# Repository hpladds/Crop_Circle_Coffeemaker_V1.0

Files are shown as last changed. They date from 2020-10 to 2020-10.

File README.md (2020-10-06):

The code for the Ridiculous Coffee Machine  (AKA Crop Circle Coffeemaker) consists of python scripts that control the movement of the machinery and one a Bash script that calls the individual python scripts at the appropriate times.

A pair of python scripts control each motor: one script (with the "cw" designation) turns the motorshaft in a clockwise direction, the second script (with a ccw designation) turns the motorshaft in a counterclockwise direction.

For example: Script "1_cw.py" turns the shaft of motor 1 in a clockwise direction. Script "1_ccw.py" turns the motorshaft in a counterclockwise direction. 

From the Linux command line the following will rotate the motor's shaft at a rate of 1 step/millisecond for 10 steps:

$ python 1_cw.py 1 10

Each motor is fitted with a pulley gear wound with a cable. As the motorshaft rotates, the cable is either reeled in or out, and each motor works as a cable actuator. Three of these cable actuators are connected to central "effector" thereby creating a "Cable Robot."

The python script, "move_dist.py" coordinates the actions of the three stepper motors (the cable actuators) so as to control the movement of the "effector." Movement of the coffee cup is acheived by placing it upon the effector and executing the move_dist.py script.

Pouring water from the kettle is controlled with the Bash script "brew_flow.sh"  

"Brew.sh" is the script that initiates the brewing.

# Crop_Circle_Coffeemaker_V1.0

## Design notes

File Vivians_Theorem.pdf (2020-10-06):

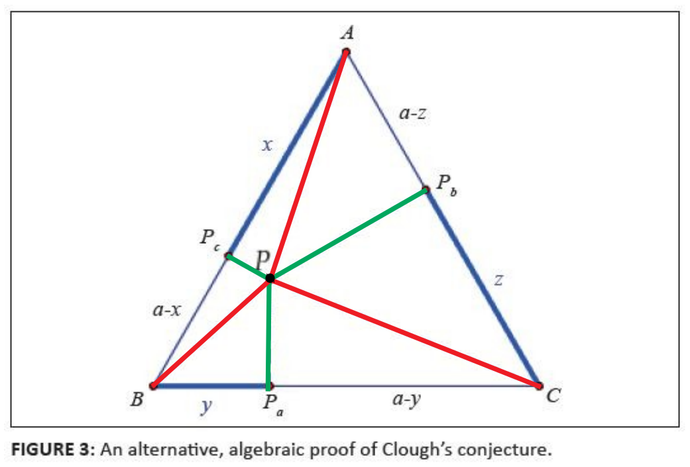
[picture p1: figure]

Viviani’s Theorem states that the sum of the lengths of the green lines will be constant irrespective of the position of P. https://en.wikipedia.org/wiki/Viviani%27s_theorem

Clough’s Theorem states that the sum of the lengths of the blue lines will also be constant irrespective of P’s position. https://ggijro1.files.wordpress.com/2013/12/art44311.pdf

Question???

Doesn’t this imply that the sum of the red lines (the hypotenuse) would also be constant irrespective of the P’s placement?

The Internet seems conspicuously empty of any confirmation of this bit of conjecture.

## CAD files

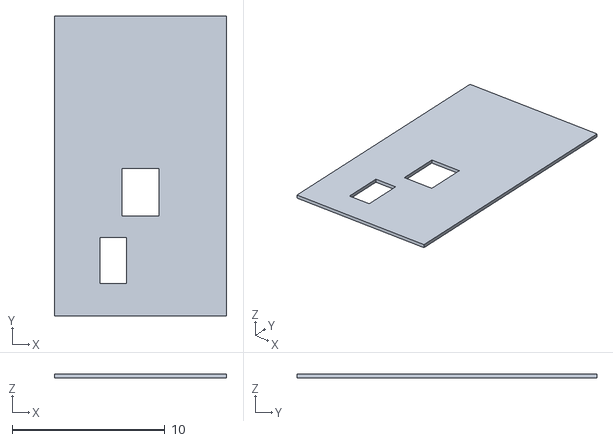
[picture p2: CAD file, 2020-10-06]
Base_Construction/STL/Bottom/Board_cutouts.stl
11.2 x 19.6 x 0.25

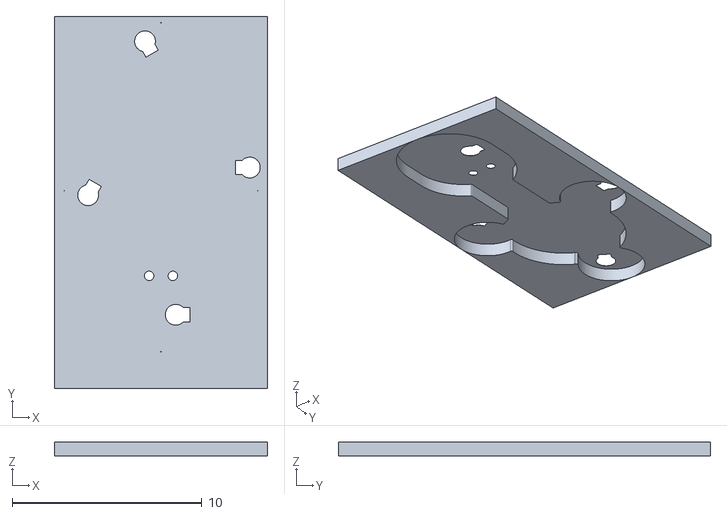
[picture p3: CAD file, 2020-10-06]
Base_Construction/STL/top/Through_holes.stl
11.2 x 19.6 x 0.76

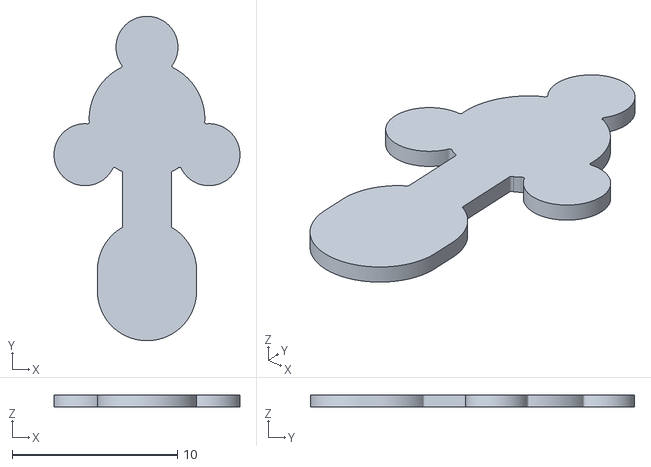
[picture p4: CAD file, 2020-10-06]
Base_Construction/Trash/Trying_To_Make_Bottom_Pockets/Push_Button_Pocket.stl
11.2 x 19.6 x 0.75

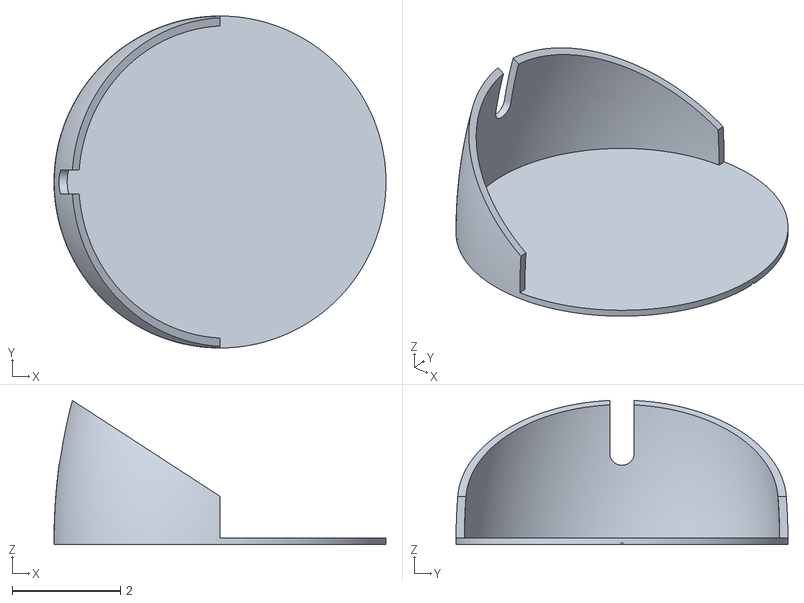
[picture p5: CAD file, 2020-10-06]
Kettle_Bracket_Platform/Kettle_Holder.stl
6.12 x 6.12 x 2.66

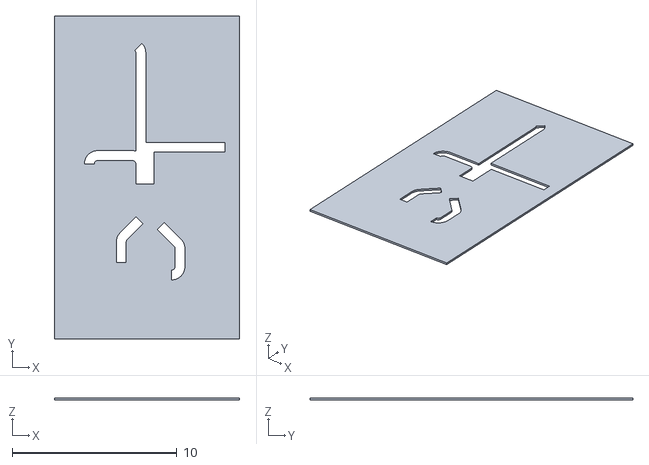
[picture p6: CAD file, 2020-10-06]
Base_Construction/STL/Bottom/wire_channel_cut_out.stl
11.2 x 19.6 x 0.125

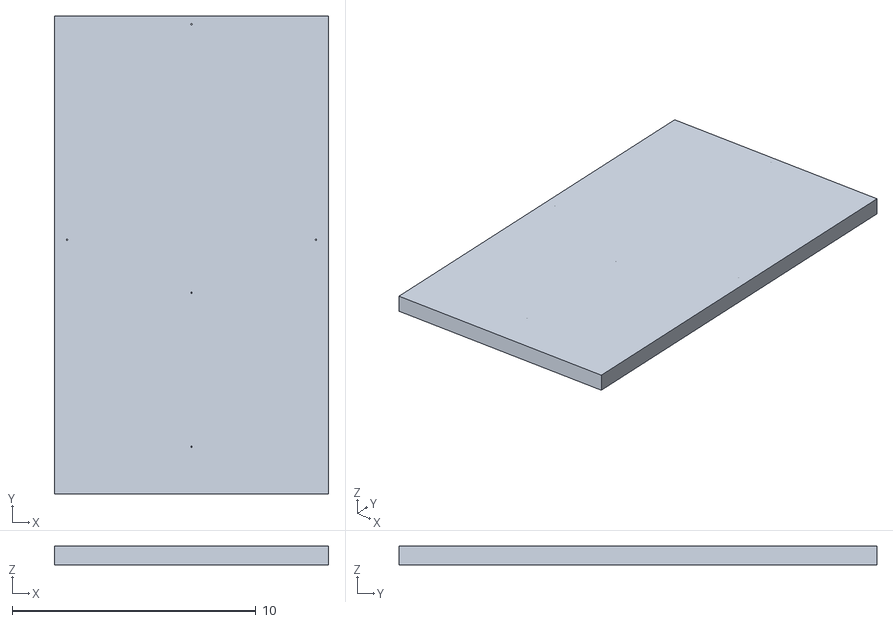
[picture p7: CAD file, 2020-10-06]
Base_Construction/STL/top/markings.stl
11.2 x 19.6 x 0.76

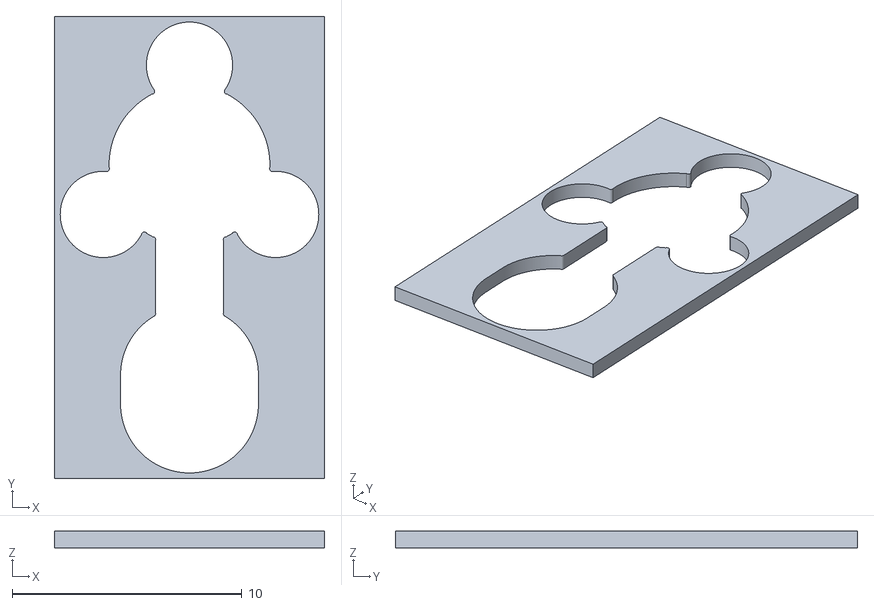
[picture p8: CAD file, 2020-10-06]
Base_Construction/STL/Bottom/Outer_Perimeter_Cut_bottom.stl
11.8 x 20.1 x 0.73

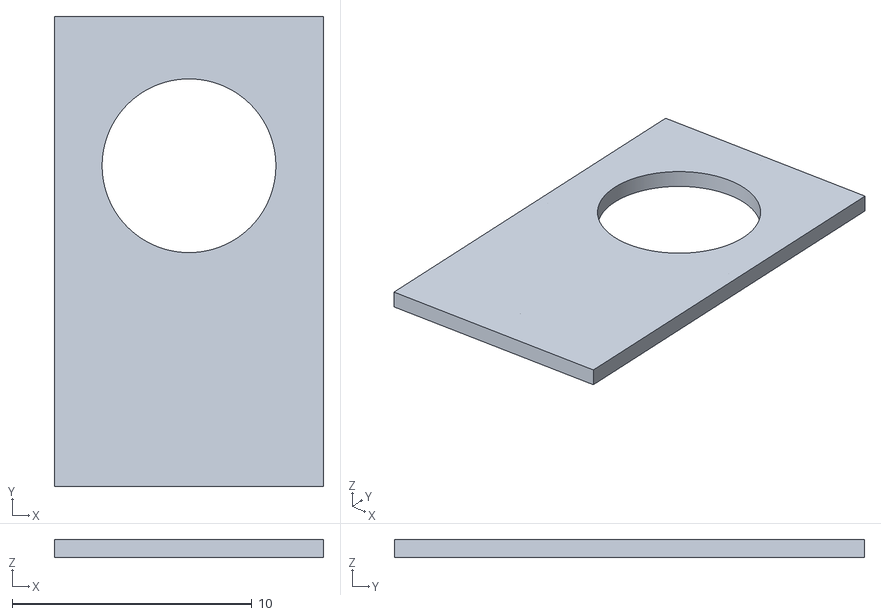
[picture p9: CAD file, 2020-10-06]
Base_Construction/STL/top/Platform.stl
11.2 x 19.6 x 0.76

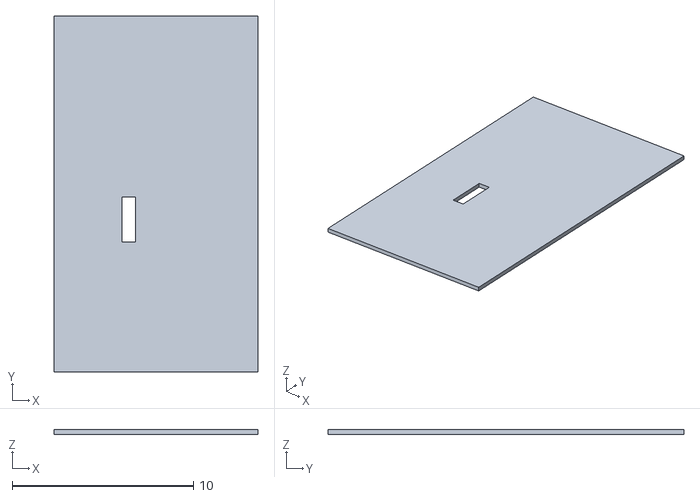
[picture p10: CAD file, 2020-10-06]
Base_Construction/STL/Bottom/Outlet_cutout.stl
11.2 x 19.6 x 0.25

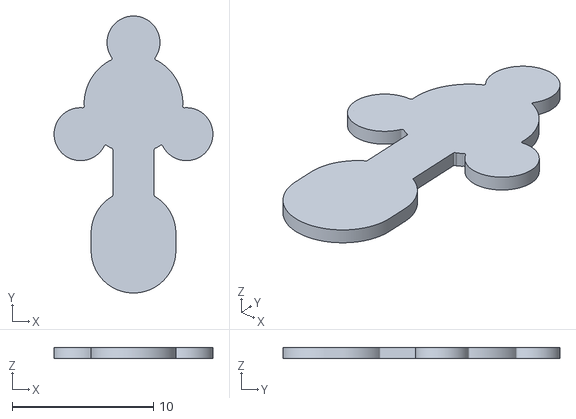
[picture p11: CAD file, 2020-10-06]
Base_Construction/Trash/Trying_To_Make_Bottom_Pockets/Channel2.stl
11.2 x 19.6 x 0.75

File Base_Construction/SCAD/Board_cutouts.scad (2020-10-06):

module channel1(){
    rotate ([0,0,270])
        rotate_extrude(angle=90, $fn = 300)
            translate([.5, .0485]) square([.6,.2247],true);
    
    translate([0,1.11,-.001])
        rotate_extrude(angle=45, $fn = 300)
            translate([.5, .0485]) square([.6,.2247],true);
    
    translate([.2,-.01,-.064])
        cube([.6, 1.125,.225],false);
    
    translate([.15, 1.243,-.064])
    rotate ([0,0,45])
        cube([.6, 1.45,.225],false);
}

module channel2(){  
    translate([-1.863, -8.75,-.064])
        cube([.6, 1.25,.225],false);
   
    translate([-1.0625, -7.5,-.001])
    rotate ([180,0,180])
        rotate_extrude(angle=45, $fn = 300)
            translate([.5, -.0485]) square([.6,.225],true);
    
      translate([-.245, -6.4,-.064])
      rotate ([0,0,135])
        cube([.6, 1.37,.225],false); 
}

module channel3(){

    translate([-.875, 4,-.001])
        rotate_extrude(angle=45, $fn = 300)
            translate([.5, 0.0485]) square([.6,.225],true);
    
        translate([-3, -2.75,-.001])
    rotate([0,0,90])
        rotate_extrude(angle=90, $fn = 300)
            translate([.5, 0.0485]) square([.6,.225],true);
    
        translate([-.875, -2.75,-.001])
        rotate_extrude(angle=90, $fn = 300)
            translate([.5, 0.0485]) square([.6,.225],true);
    
    translate([-.675, -3.975,-.064])
        cube([.6, 8,.225],false);
    
    translate([4.75, -2.04,-.064])
    rotate([0,0,90])
        cube([.6, 5,.225],false);
    
    translate([-.175, -3.975,-.064])
        cube([.6, 2.5,.225],false);
    
           
    translate([-.8, -2.55,-.064])
    rotate([0,0,90])
        cube([.6, 2.25,.225],false);   
}

module riser2_cutout(){ // riser for kettle
    union(){
        translate([-.625, 0, .375])
        cylinder(1, r=.25, center = true, $fn=30);
        translate([.625, 0, .375])
        cylinder(1, r=.25, center = true, $fn=30);
    }
}

module button_cutout(){ // push botton cutout
  
    translate([.25, -.5, -.07]) 
       cube([1.75, 3, .66], center = false);
      
    translate([.5, 1.75, .5125]) //control button
        button();
  
    translate([.5, 0, .5125])  // north button
        button();
    
    translate([.875, .5, .5125]) // west button
        button();
    
    translate([.125, .5, .5125]) // east button
        button();
    
    translate([.5, 1, .5125])
        button();          // south button    
}
    
module button(){ // push botton 

        translate([.625, 0, .166])
        color( "black", 1.0 )
            cylinder(.1875, r=.0625, center = true, $fn=30);
    
        translate([.625, 0, 0])
             cube([.25, .4375, .156], center = true);  
}

module StepMotor28BYJ_Cutout(){
    union(){
        translate  ([-.315,0, 0])
            cylinder(h = 1, r = .55, center = true, $fn = 32);
        translate([-.815, 0, 0])
            cube([.5, .75, 1], center = true);
        }       
}

module motor_bases() {
    
difference (){
union(){
    translate([0, 2.89, .375])
        cylinder(.75, r=3.5, $fn=300, center=true); // cup platform
        
    translate([0, -2, .375])
        cube([2.9375, 4, .75], center = true); // center arm
    
    translate([-1.965, .2025, .375])
    rotate([0, 0, 100])
        cube([.5, 1, .75], center = true); // west arm filler
   
    translate([-3.5, 2.37, .375])
    rotate([0, 0, 317])
        cube([.5, 1, .75], center = true); // west arm filler 
   
    translate([1.362, 5.9, .375])
    rotate([0, 0, 19])
        cube([.5, 1, .75], center = true); // center/ north arm filler
        
    translate([-1.362, 5.9, .375])
    rotate([0, 0, 341])
        cube([.5, 1, .75], center = true); // center/ north arm filler 
    
    translate([1.965, .2025, .375])
    rotate([0, 0, 80])
        cube([.5, 1, .75], center = true); // east arm filler 
    
    translate([3.5, 2.37, .375])
    rotate([0, 0, 43])
        cube([.5, .5, .75], center = true); // east arm filler 
           
    translate([-1.27, -.2, .375])
    rotate([0, 0, 33])
        cube([.5, .5, .75], center = true); // center arm filler north west
    
    translate([1.27, -.2, .375])
    rotate([0, 0, -30])
        cube([.5, .5, .75], center = true); // center arm filler north east
       
    translate([-1.27, -3.72, .375])
    rotate([0, 0, 332])
        cube([.5, .5, .75], center = true); // center arm filler south west 
    
    translate([1.27, -3.72, .375])
    rotate([0, 0, 28])
        cube([.5, .5, .75], center = true); // center arm filler south east 
    
    translate([0, 5.774, .375])
    rotate([0, 0, 0])
        cube([2.0625, 5.774, .75], center=true); // north arm
        
    translate([2.5, 1.45, .375])
    rotate([0, 0, 60])
        cube([2.0625, 5.774, .75], center=true); // east arm  
      
    translate([-2.5, 1.45, .375])
    rotate([0, 0, 120])
        cube([2.0625, 5.774, .75], center=true); // west arm
    
    translate([0, 7.245, 0])
        cylinder(.75, r=1.875, $fn=300, center=false); // north outcrop
    
    translate([-3.75, .75, 0])
        cylinder(.75, r=1.875, $fn=300, center=false); // west outcrop
    
    translate([3.75, .75, 0])
        cylinder(.75, r=1.875, $fn=300, center=false); // east outcrop

    translate([0, -8.5, 0]) // base for kettle
        hull(){                   
            translate([0, 1, .375])
            cylinder(.75, r=3, $fn=300, center=true); 
            translate([0, 2.25, .375])
            cylinder(.75, r=3, $fn=300, center=true); 
    }
}

    translate([-1.593, -.347, .375])
        cylinder(.875, r=.125, $fn=30, center=true); // Round corner cent. platform north west

    translate([1.593, -.347, .375])
        cylinder(.875, r=.125, $fn=30, center=true); // Round corner cent. platform north east

    translate([-1.593, -3.567, .375])
        cylinder(.875, r=.125, $fn=30, center=true); // Round corner cent. platform south west

    translate([1.593, -3.567, .375])
        cylinder(.875, r=.125, $fn=30, center=true); // Round corner cent. platform south east

    translate([-1.965, -.14, .375])
        cylinder(.875, r=.125, $fn=30, center=true); // Round corner west outcrop

    translate([-3.609, 2.739, .375])
        cylinder(.875, r=.125, $fn=30, center=true); // Round corner west outcrop

    translate([1.966, -.1375, .375])
        cylinder(.875, r=.125, $fn=30, center=true); // Round corner east outcrop

    translate([3.609, 2.739, .375])
        cylinder(.875, r=.125, $fn=30, center=true); // Round corner east outcrop

    translate([1.639, 6.106, .375])
        cylinder(.875, r=.125, $fn=30, center=true); // Round corner north outcrop
        
    translate([-1.639, 6.106, .375])
        cylinder(.875, r=.125, $fn=30, center=true); // Round corner north outcrop     
}
}

///////////////// CODE BEGINS//////////////////

difference() {
    
    translate([-5.625, -13.39, 0])
        cube([11.25, 19.62,.25],false); 
    
    //translate([0,-2.89,0])
      //  motor_bases();
  /* 
    translate([1.5,-9, -.01])
        channel1(); 
   
    translate([0, 0, 0])
        channel2(); 
    
    translate([0, 0, 0])
        channel3();
*/
    translate([-2.9, -10.75, .065])
        button_cutout(); //This has been verified.
   
//    translate([-1.5, -4.987, .145]) 
//        cube([ .75, 2.5, .3], center=true); // outlet cutout
    
    translate([0, -5.3, .24]) 
        cube([ 2.4375, 3.126, .5], center=true); // board cutout

    translate([0, 0, .501])
        cylinder(.25, r=3.625, $fn=30); //removes material from platform for effector
    
////Through Holes//////
 /*  
    translate([-1, 5.193, .375]) //north stepper cutout
    rotate ([0, 180, 300])    
        StepMotor28BYJ_Cutout();

    translate ([-4.0003, -3.4675, .375]) //west stepper cutout
    rotate ([0, 180, 60])
        StepMotor28BYJ_Cutout();
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

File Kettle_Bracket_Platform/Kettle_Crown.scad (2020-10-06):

module Ket_Crown  () {

difference() {     
difference () {
    resize([6.3,0,11.5])
        sphere ( d=6, $fn = 100);
    translate ([0,0,-3])
    cube (size = [7,7,6], center = true);
    translate ([0,-3,2.95])
    cube (size = [7,6,7], center = true);
}

translate ([0,-.01,-.0625])
scale ([.9,.9,.965])difference () {
    resize([6.7,6.3,11.7])
    sphere ( d=6, $fn = 100);
    translate ([0,0,-3])
    cube (size = [7,7,6], center = true);
    translate ([0,-3,2.95])
    cube (size = [7,6,7], center = true);
}
    translate ([0,0,5])
    rotate ([33,0,0])
    cube (size = [7,7,7], center = true);
    
    translate ([0,3,.6])
    rotate ([90,0,0])
    cylinder (1, d1=.5, d2=.5, $fn = 100, center = true);

    translate ([0,2.75,3.08])
    cube (size = [.5,1,5], center = true);
   }
     
}



module Ket_Crown_Base  () {

   translate ([0,0,.0625])
   scale ([.942,.95,.965])
   resize([6.7,6.3,.125])
   cylinder (d1=1, d2=1, h=.125, $fn = 100, center = true);
  }


union () {
    translate ([0,0,.125])
    rotate([0,0,135])
Ket_Crown ();
    rotate([0,0,135])
Ket_Crown_Base ();
}

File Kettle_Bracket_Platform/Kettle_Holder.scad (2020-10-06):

seg = 300;

module Ket_shell_exterior(){
    resize([0,0,11.5])
        sphere ( d=6.125, $fn = seg);   
}

module Ket_shell_interior(){
    scale ([.95, .95, .985])
        Ket_shell_exterior();
}

module Spout_opening () {
    translate ([0,0,5])
    rotate ([0,33,0])
        cube (size = [7,7,7], center = true); //Trim top of sphere(s)
    
    translate ([-3,0,1.625])
    rotate ([90,0,90])
        cylinder (1, d1=.45, d2=.45, $fn = seg, center = true);

    translate ([-2.75,0,3.08])
        cube (size = [1,.45, 2.9], center = true);    
}
    
module base (){
difference () {    
    scale ([1, 1, 1])
        cylinder (.125, d1=6.125, d2=6.125, $fn = seg, center = true); 
 
    translate ([-3.1, 0, -.2])  
    rotate ([45, 0, 0])
        cube (size = [.25,.25, .25], center = true);//center mark
    
    translate ([3.1, 0, -.2])  
    rotate ([45, 0, 0])
        cube (size = [.25,.25, .25], center = true);  //center mark 
}
}
////////BEGIN////////

difference () {
    Ket_shell_exterior();
    Ket_shell_interior();
    Spout_opening ();
    
    translate([3, 0, 1])  
        cube (size = [6,8,4], center = true); //Trim side of sphere(s)
    
    translate([-4, -4, -8.0625])
        cube (size = [8,8,8], center = false); //Trim bottom of sphere(s)
    
    translate ([-3.1, 0, -.2])  
    rotate ([45, 0, 0])
        cube (size = [.25,.25, .25], center = true); //center mark... again!
}

base ();

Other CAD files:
Base_Construction/Trash/Trying_To_Make_Bottom_Pockets/Outlet.stl
Base_Construction/Trash/Trying_To_Make_Bottom_Pockets/Channel1.stl
Base_Construction/Trash/Trying_To_Make_Bottom_Pockets/Channel3.stl
Base_Construction/Trash/Trying_To_Make_Bottom_Pockets/Motherboard_Pocket.stl
Kettle_Bracket_Platform/Kettle_Crown2.scad
Base_Construction/SCAD/Base.scad
Base_Construction/SCAD/Base_For_Channels.scad
Base_Construction/SCAD/Best_Todate_Sept_25.scad
Base_Construction/SCAD/Outlet_cutout.scad
Base_Construction/SCAD/wire_channel_cut_out.scad
Pulleys/Kettle_Pulley.scad
Pulleys/Kettle_Pulley_hand_Measured.scad

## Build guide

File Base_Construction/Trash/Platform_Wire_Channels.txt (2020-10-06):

( File created: Monday September 28 2020 - 01:39 PM)
( for Mach2/3 from Vectric )
( Material Size)
( X= 11.250, Y= 19.620, Z= 0.125)
()
(Toolpaths used in this file:)
(Tools used in this file: )
(1 = End Mill {1/4"})
N110G00G20G17G90G40G49G80
N120G70G91.1
N130T1M06
N140 (End Mill {1/4"})
N150G00G43Z1.0000H1
N160S16000M03
N180()
N190G94
N200X0.0000Y0.0000F40.0
N2920G00X5.4698Y8.1796Z1.000
N2930G1Z-0.125F10.0
N2940G1X5.5350Y8.1848F40.0
N2950G2X5.5275Y8.2728I0.5135J0.0880
N2960G1Y9.6826
N2970G1X5.4698
N2980G1Y8.9382
N2990G2X5.4195Y8.7147I-0.5210J0.0000
N3000G1X5.3892Y8.6511
N3010G1X5.3764Y8.6273
N3020G1X5.3508Y8.5849
N3030G1X5.3264Y8.5501
N3040G2X5.4698Y8.1911I-0.3776J-0.3590
N3050G1X5.4698Y8.1796
N3060G1X5.3708Y8.0490
N3070G2X5.5433Y8.0858I0.1724J-0.3852
N3080G1X5.6702
N3090G2X5.6265Y8.2728I0.3784J0.1869
N3100G1Y9.7816
N3110G1X5.3708
N3120G1Y8.9382
N3130G2X5.3300Y8.7572I-0.4220J0.0000
N3140G1X5.3009Y8.6959
N3150G1X5.2893Y8.6744
N3160G1X5.2686Y8.6401
N3170G1X5.2509Y8.6137
N3180G1X5.2204Y8.5757
N3190G1X5.1863Y8.5399
N3200G2X5.3708Y8.1911I-0.2375J-0.3489
N3210G1X5.3708Y8.0490
N3220G1X5.2718Y7.8389
N3230G2X5.5433Y7.9868I0.2714J-0.1751
N3240G1X5.8983
N3250G2X5.7255Y8.2728I0.1502J0.2859
N3260G1Y9.8806
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
%

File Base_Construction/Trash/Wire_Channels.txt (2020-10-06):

( Wire_Channels )
( File created: Monday September 28 2020 - 01:35 PM)
( for Mach2/3 from Vectric )
( Material Size)
( X= 11.250, Y= 19.620, Z= 0.125)
()
(Toolpaths used in this file:)
(Pocket 1)
(Pocket 2)
(Pocket 3)
(Tools used in this file: )
(1 = End Mill {1/4"})
N120G00G20G17G90G40G49G80
N130G70G91.1
N140T1M06
N150 (End Mill {1/4"})
N160G00G43Z1.0000H1
N170S16000M03
N180(Toolpath:- Pocket 1)
N190()
N200G94
N210X0.0000Y0.0000F40.0
N220G00X6.6727Y12.8594Z0.2000
N230G1Z-0.0625F10.0
N240G1X7.6001Y13.7892F40.0
N250G1X7.6369Y13.8638
N260G1X7.6442Y13.8801
N270G1X7.6606Y13.9203
N280G1X7.6791Y13.9731
N290G1X7.6971Y14.0408
N300G1Y15.3076
N310G1X7.6828Y15.3621
N320G1X7.6735Y15.3936
N330G1X7.6608Y15.4302
N340G1X7.6396Y15.4831
N350G1X7.6297Y15.5031
N360G1X7.6223Y15.5151
N370G1X7.6116Y15.5307
N380G1X7.5981Y15.5486
N390G1X7.5822Y15.5681
N400G1X7.5645Y15.5885
N410G1X7.5454Y15.6093
N420G1X7.5253Y15.6300
N430G1X7.5046Y15.6501
N440G1X7.4838Y15.6692
N450G1X7.4634Y15.6869
N460G1X7.4439Y15.7027
N470G1X7.4259Y15.7163
N480G1X7.4103Y15.7270
N490G1X7.3894Y15.7391
N500G1X7.3616Y15.7515
N510G1X7.3426Y15.7589
N520G1Y15.5878
N530G1X7.3538Y15.5807
N540G1X7.3883Y15.5541
N550G1X7.4074Y15.5373
N560G1X7.4244Y15.5210
N570G1X7.4410Y15.5035
N580G1X7.4573Y15.4846
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
(Pocket 2)
()
N2290G00X4.9565Y12.5267Z0.2000
N2300G1Z-0.0625F10.0
N2310G1X5.0615Y12.6317F40.0
N2320G1X4.2100Y13.4839
N2330G2X4.1442Y13.6429I0.1592J0.1590
N2340G1X4.1441Y14.6890
N2350G1X4.1393Y14.7611
N2360G1X3.9850
N2370G1X3.9854Y13.6951
N2380G1X4.0059Y13.6001
N2390G1X4.0172Y13.5609
N2400G1X4.0323Y13.5167
N2410G1X4.0475Y13.4786
N2420G1X4.0838Y13.4026
N2430G1X4.9565Y12.5267
N2440G1X4.9564Y12.3852
N2450G1X5.2028Y12.6316
N2460G1X4.2808Y13.5546
N2470G2X4.2442Y13.6429I0.0884J0.0883
N2480G1X4.2441Y14.6923
N2490G1X4.2329Y14.8611
N2500G1X3.8850
N2510G1X3.8854Y13.6847
N2520G1X3.9089Y13.5755
N2530G1X3.9218Y13.5307
N2540G1X3.9385Y13.4821
N2550G1X3.9558Y13.4386
N2560G1X4.0011Y13.3440
N2570G1X4.9564Y12.3852
N2580G00Z0.2000
N2590G00X4.9565Y12.5267
N2600G1Z-0.1250F10.0
N2610G1X5.0615Y12.6317F40.0
N2620G1X4.2100Y13.4839
N2630G2X4.1442Y13.6429I0.1592J0.1590
N2640G1X4.1441Y14.6890
N2650G1X4.1393Y14.7611
N2660G1X3.9850
N2670G1X3.9854Y13.6951
N2680G1X4.0059Y13.6001
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
(Pocket 3)
()
N2920G00X5.4698Y8.1796Z0.2000
N2930G1Z-0.0625F10.0
N2940G1X5.5350Y8.1848F40.0
N2950G2X5.5275Y8.2728I0.5135J0.0880
N2960G1Y9.6826
N2970G1X5.4698
N2980G1Y8.9382
N2990G2X5.4195Y8.7147I-0.5210J0.0000
N3000G1X5.3892Y8.6511
N3010G1X5.3764Y8.6273
N3020G1X5.3508Y8.5849
N3030G1X5.3264Y8.5501
N3040G2X5.4698Y8.1911I-0.3776J-0.3590
N3050G1X5.4698Y8.1796
N3060G1X5.3708Y8.0490
N3070G2X5.5433Y8.0858I0.1724J-0.3852
N3080G1X5.6702
N3090G2X5.6265Y8.2728I0.3784J0.1869
N3100G1Y9.7816
N3110G1X5.3708
N3120G1Y8.9382
N3130G2X5.3300Y8.7572I-0.4220J0.0000
N3140G1X5.3009Y8.6959
N3150G1X5.2893Y8.6744
N3160G1X5.2686Y8.6401
N3170G1X5.2509Y8.6137
N3180G1X5.2204Y8.5757
N3190G1X5.1863Y8.5399
N3200G2X5.3708Y8.1911I-0.2375J-0.3489
N3210G1X5.3708Y8.0490
N3220G1X5.2718Y7.8389
N3230G2X5.5433Y7.9868I0.2714J-0.1751
N3240G1X5.8983
N3250G2X5.7255Y8.2728I0.1502J0.2859
N3260G1Y9.8806
N3270G1X5.2718
N3280G1Y8.9382
N3290G2X5.2406Y8.7997I-0.3230J0.0000
N3300G1X5.2126Y8.7407
N3310G1X5.1949Y8.7080
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
%

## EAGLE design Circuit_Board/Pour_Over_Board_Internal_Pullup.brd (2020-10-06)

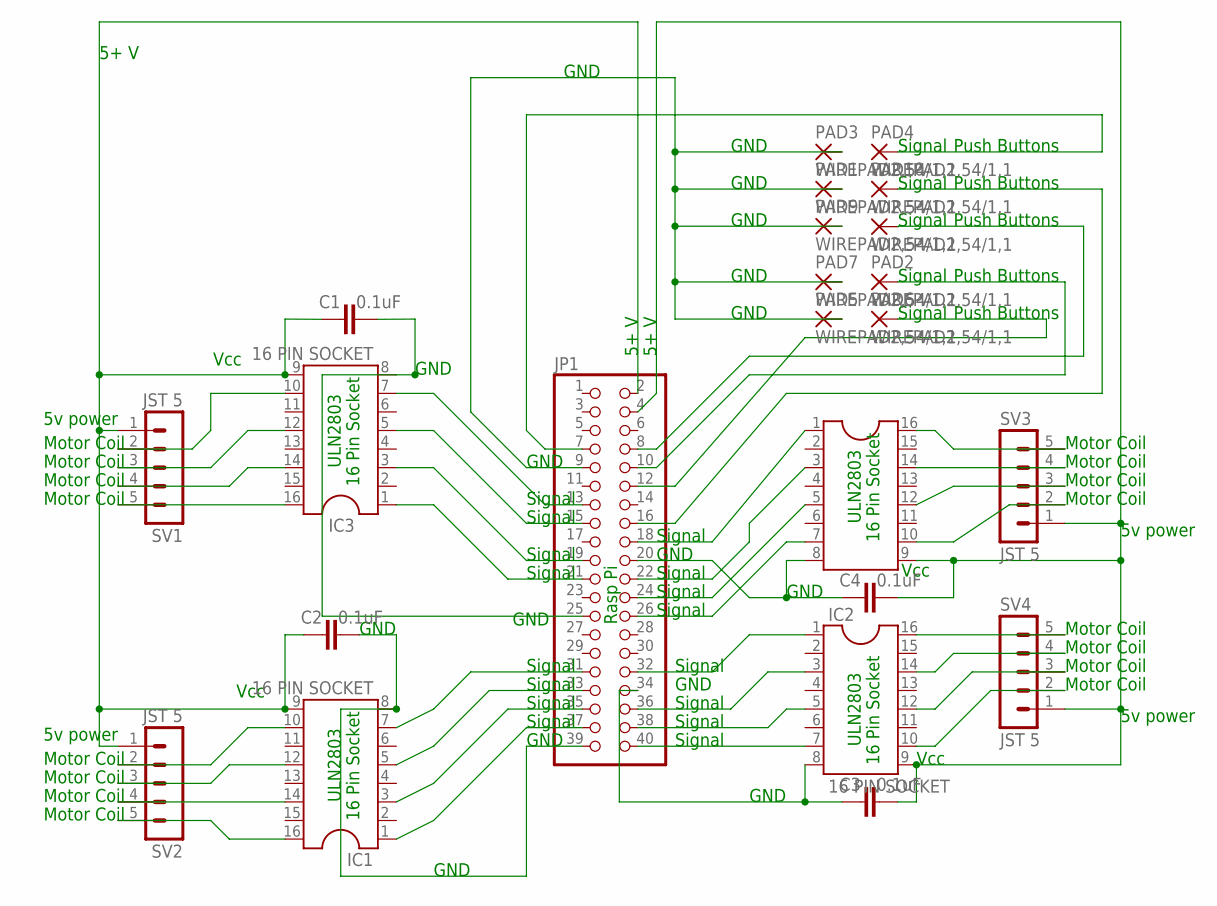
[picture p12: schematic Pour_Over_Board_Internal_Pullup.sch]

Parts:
C1, C2, C3, C4: 0.1uF; CAP-PTH-SMALL-KIT
IC1, IC2, IC3, IC4: 16 PIN SOCKET; SOCKET-16
JP1: RaspPiZero; 2X20
PAD1, PAD2, PAD3, PAD4, PAD5, PAD6, PAD7, PAD8, PAD9, PAD10: WIREPAD2,54/1,1; 2,54/1,1
SV1, SV2, SV3, SV4: JST 5; MA05-1

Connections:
unnamed: IC3.7, JP1.13
unnamed: C3.1, IC2.8, JP1.34
unnamed: JP1.12, PAD6.1
unnamed: C1.1, C2.1, IC1.9, IC3.9, JP1.2, SV1.1, SV2.1
unnamed: IC3.3, JP1.19
unnamed: IC3.1, JP1.21
unnamed: IC1.1, JP1.37
unnamed: IC1.3, JP1.35
unnamed: IC2.1, JP1.32
unnamed: IC2.3, JP1.36
unnamed: IC2.5, JP1.38
unnamed: IC2.7, JP1.40
unnamed: IC4.1, JP1.18
unnamed: IC4.3, JP1.22
unnamed: IC4.10, SV3.2
unnamed: IC4.12, SV3.3
unnamed: IC4.14, SV3.4
unnamed: IC4.16, SV3.5
unnamed: IC2.10, SV4.2
unnamed: IC2.12, SV4.3
unnamed: IC2.14, SV4.4
unnamed: IC2.16, SV4.5
unnamed: IC3.16, SV1.5
unnamed: JP1.16, PAD10.1
unnamed: IC3.14, SV1.4
unnamed: IC3.12, SV1.3
unnamed: IC4.5, JP1.24
unnamed: IC4.7, JP1.26
unnamed: IC1.5, JP1.33
unnamed: IC1.7, JP1.31
unnamed: IC3.10, SV1.2
unnamed: IC1.16, SV2.5
unnamed: IC1.14, SV2.4
unnamed: IC3.5, JP1.15
unnamed: C2.2, IC1.8, JP1.39
unnamed: IC1.12, SV2.3
unnamed: IC1.10, SV2.2
unnamed: C4.1, IC4.8, JP1.20
unnamed: C1.2, IC3.8, JP1.25
unnamed: C3.2, C4.2, IC2.9, IC4.9, JP1.4, SV3.1, SV4.1
unnamed: JP1.8, PAD8.1
unnamed: JP1.9, PAD1.1, PAD3.1, PAD5.1, PAD7.1, PAD9.1
unnamed: JP1.10, PAD2.1
unnamed: JP1.7, PAD4.1

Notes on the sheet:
5+ V
ULN2803
16 Pin Socket
5v power
Motor Coil
Signal
Rasp Pi
GND
Vcc
Push Buttons

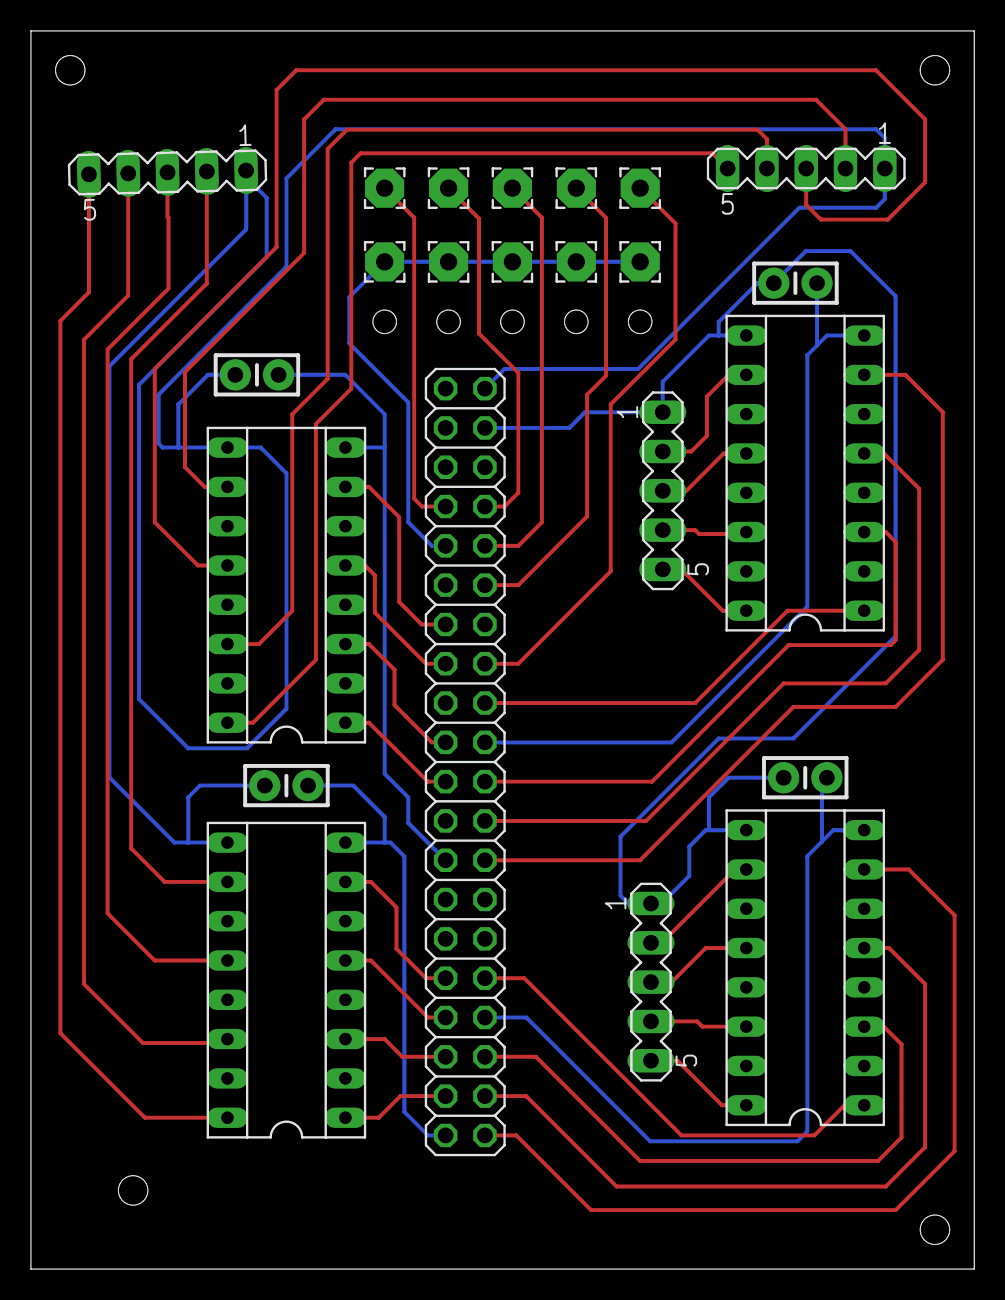
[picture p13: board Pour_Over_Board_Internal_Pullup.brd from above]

Board: 2 copper layers, 61.0 x 80.0 mm, 23 parts (0 on the bottom side), 44 nets.

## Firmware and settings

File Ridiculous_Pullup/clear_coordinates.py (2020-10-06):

import RPi.GPIO as GPIO
import time
import sys
import math
#from  math import cos, sin, radians, sqrt, pow
 
GPIO.setmode(GPIO.BCM)
GPIO.setwarnings(False)
 
coil_A_1_pin1 = 27 #orange  
coil_A_2_pin1 = 22 #yellow
coil_B_1_pin1 = 10 #pink
coil_B_2_pin1 = 9  #blue

coil_A_1_pin3 = 21 #orange
coil_A_2_pin3 = 20 #yellow
coil_B_1_pin3 = 16 #purple/pink
coil_B_2_pin3 = 12 #blue

coil_A_1_pin4 = 7 #orange
coil_A_2_pin4 = 8 #yellow
coil_B_1_pin4 = 25 #purple/pink
coil_B_2_pin4 = 24 #blue

delay = float(1)#Can't be smaller than 1 or miss steps. If increase, slows down movements
stepSize = 0.005737 #inches per step-- need to change this if change spool size on steppers
xHome = 4.9125 #inches-- home (center of triangle)
yHome = 2.9375 #inches-- home (center of triangle)
x = xHome
y = yHome
X3 = 5.01 #position of stepper3
Y3 = 8.69 #position of stepper3
X4 = 9.825 #position of stepper4
step1Leftover = 0
step3Leftover = 0
step4Leftover = 0

#if you run file without current_coords.txt in folder (or not accurate)
#comment out from here
#F = open("/home/pi/Ridiculous/current_coords.txt","r")
#x = float(F.readline())
#y = float(F.readline())
#step1Leftover = float(F.readline())
#step3Leftover = float(F.readline())
#step4Leftover = float(F.readline())

#F.close()
#to here -- then uncomment for further runs


#distance = float(sys.argv [1]) #inches
#angle = float(sys.argv [2]) #degrees
#delay = float (sys.argv [1])
#steps = sys.argv [2]

GPIO.setup(coil_A_1_pin1, GPIO.OUT)
GPIO.setup(coil_A_2_pin1, GPIO.OUT)
GPIO.setup(coil_B_1_pin1, GPIO.OUT)
GPIO.setup(coil_B_2_pin1, GPIO.OUT)
GPIO.setup(coil_A_1_pin3, GPIO.OUT)
GPIO.setup(coil_A_2_pin3, GPIO.OUT)
GPIO.setup(coil_B_1_pin3, GPIO.OUT)
GPIO.setup(coil_B_2_pin3, GPIO.OUT)
GPIO.setup(coil_A_1_pin4, GPIO.OUT)
GPIO.setup(coil_A_2_pin4, GPIO.OUT)
GPIO.setup(coil_B_1_pin4, GPIO.OUT)
GPIO.setup(coil_B_2_pin4, GPIO.OUT)


#deltaX = distance*math.cos(math.radians(angle))
#deltaY = distance*math.sin(math.radians(angle))
#deltaL1 = deltaX*sqrt(1+pow((deltaY/deltaX),2))
#if (deltaX == 0)
#deltaL1 = deltaX*math.sqrt(1+math.pow((deltaX/deltaY),2))
#The problem here  seems to be in the square root and syntax for float vs int.

#print deltaX
#print deltaY
#print deltaL1

def moveStep(delay, step1, step3, step4):  
  if step1 == 1:
    setStep1(1, 0, 0, 0)
  else:
    if step1 == -1:
      setStep1(1, 0, 0, 1)
  if step3 == 1:
    setStep3(1, 0, 0, 0)
  else:
    if step3 == -1:
      setStep3(1, 0, 0, 1)
  if step4 == 1:
    setStep4(1, 0, 0, 0)
  else:
    if step4 == -1:
      setStep4(1, 0, 0, 1)
    #first step done
  time.sleep(delay)
  if step1 == 1:
    setStep1(1, 1, 0, 0)
  else:
    if step1 == -1:
      setStep1(0, 0, 0, 1)
  if step3 == 1:      
    setStep3(1, 1, 0, 0)
  else:
    if step3 == -1:
      setStep3(0, 0, 0, 1)  
  if step4 == 1:
    setStep4(1, 1, 0, 0)
  else:
    if step4 == -1:
      setStep4(0, 0, 0, 1)
    #second step done
  time.sleep(delay)
  if step1 == 1:
    setStep1(0, 1, 0, 0)
  else:
    if step1 == -1:
      setStep1(0, 0, 1, 1)
  if step3 == 1:
    setStep3(0, 1, 0, 0)
  else:
    if step3 == -1:
      setStep3(0, 0, 1, 1)      
  if step1 == 1:
    setStep1(0, 1, 0, 0)
  else:
    if step1 == -1:
      setStep1(0, 0, 1, 1)
    #third step done
  time.sleep(delay)
  if step1 == 1:
    setStep1(0, 1, 1, 0)
  else:
    if step1 == -1:
      setStep1(0, 0, 1, 0)
  if step3 == 1:
    setStep3(0, 1, 1, 0)
  else:
    if step3 == -1:
      setStep3(0, 0, 1, 0)      
  if step4 == 1:
    setStep4(0, 1, 1, 0)
  else:
    if step4 == -1:
      setStep4(0, 0, 1, 0)
    #fourth step done
  time.sleep(delay)
  if step1 == 1:
    setStep1(0, 0, 1, 0)
  else:
    if step1 == -1:
      setStep1(0, 1, 1, 0)
  if step3 == 1:
    setStep3(0, 0, 1, 0)
  else:
    if step3 == -1:
      setStep3(0, 1, 1, 0)      
  if step4 == 1:
    setStep4(0, 0, 1, 0)
  else:
    if step4 == -1:
      setStep4(0, 1, 1, 0)
    #fifth step done
  time.sleep(delay)
  if step1 == 1:
    setStep1(0, 0, 1, 1)
  else:
    if step1 == -1:
      setStep1(0, 1, 0, 0)
  if step3 == 1:
    setStep3(0, 0, 1, 1)
  else:
    if step3 == -1:
      setStep3(0, 1, 0, 0)
  if step4 == 1:
    setStep4(0, 0, 1, 1)
  else:
    if step4 == -1:
      setStep4(0, 1, 0, 0)
    #sixth step done
  time.sleep(delay)
  if step1 == 1:
    setStep1(0, 0, 0, 1)
  else:
    if step1 == -1:
      setStep1(1, 1, 0, 0)
  if step3 == 1:
    setStep3(0, 0, 0, 1)
  else:
    if step3 == -1:
      setStep3(1, 1, 0, 0)      
  if step4 == 1:
    setStep4(0, 0, 0, 1)
  else:
    if step4 == -1:
      setStep4(1, 1, 0, 0)
    #seventh step done
  time.sleep(delay)
  if step1 == 1:
    setStep1(1, 0, 0, 1)
  else:
    if step1 == -1:
      setStep1(1, 0, 0, 0)
  if step3 == 1:
    setStep3(1, 0, 0, 1)
  else:
    if step3 == -1:
      setStep3(1, 0, 0, 0)      
  if step4 == 1:
    setStep4(1, 0, 0, 1)
  else:
    if step4 == -1:
      setStep4(1, 0, 0, 0)
    #eigth step done
  time.sleep(delay)

def setStep1(w1, w2, w3, w4):
  GPIO.output(coil_A_1_pin1, w1) 
  GPIO.output(coil_A_2_pin1, w2) 
  GPIO.output(coil_B_1_pin1, w3) 
  GPIO.output(coil_B_2_pin1, w4) 

def setStep3(w1, w2, w3, w4):
  GPIO.output(coil_A_1_pin3, w1) 
  GPIO.output(coil_A_2_pin3, w2) 
  GPIO.output(coil_B_1_pin3, w3) 
  GPIO.output(coil_B_2_pin3, w4) 

def setStep4(w1, w2, w3, w4):
  GPIO.output(coil_A_1_pin4, w1) 
  GPIO.output(coil_A_2_pin4, w2) 
  GPIO.output(coil_B_1_pin4, w3) 
  GPIO.output(coil_B_2_pin4, w4) 

def moveLine (distance, angle):
  #steps = int(distance/stepSize) #need to add the remainder to loffsets for next move
  distance = float(distance)
  angle = float(angle)
  steps = int(abs(distance/stepSize))
  deltaX = distance*math.cos(math.radians(angle))
  deltaY = distance*math.sin(math.radians(angle))
  global x
  global y
  global step1Leftover
  global step3Leftover
  global step4Leftover
  
  for i in range(0, steps):
    step1 = 0
    step3 = 0
    step4 = 0
    deltaL1 = (x/math.sqrt(math.pow(x,2)+math.pow(y,2)))*(deltaX/steps)+(y/math.sqrt(math.pow(x,2)+math.pow(y,2)))*((deltaY/steps))

    deltaL1 = deltaL1+step1Leftover
    #print "Delta1: "
    #print deltaL1
    #print "step1Leftover: "
    #print step1Leftover
    if deltaL1 >= stepSize:
      step1 = 1
      step1Leftover = deltaL1-stepSize #deltaL1%stepSize
    elif deltaL1 <= -stepSize:
      step1 = -1
      step1Leftover = deltaL1+stepSize #deltaL1%-stepSize
    else:
      step1Leftover = deltaL1
      #print "1 didn't move"
      
    deltaL3 = -((X3-x)/math.sqrt(math.pow(x,2)-2*X3*x+math.pow(y,2)-2*Y3*y+math.pow(X3,2)+math.pow(Y3,2)))*(deltaX/steps)-((Y3-y)/math.sqrt(math.pow(x,2)-2*X3*x+math.pow(y,2)-2*Y3*y+math.pow(X3,2)+math.pow(Y3,2)))*(deltaY/steps)
    #print "Delta3: "
    #print deltaL3
    deltaL3 = deltaL3+step3Leftover

    if deltaL3 >= stepSize:
      step3 = 1
      step3Leftover = deltaL3-stepSize #deltaL3%stepSize
    elif deltaL3 <= -stepSize:
        step3 = -1
        step3Leftover = deltaL3+stepSize #deltaL3%-stepSize
    else:
      step3Leftover = deltaL3
      #print "3 didn't move"
      
    deltaL4 = -((X4-x)/math.sqrt(math.pow(x,2)-2*X4*x+math.pow(y,2)+math.pow(X4,2)))*(deltaX/steps)+(y/(math.sqrt(math.pow(x,2)-2*X4*x+math.pow(y,2)+math.pow(X4,2))))*(deltaY/steps)
    #print "Delta4: "
    #print deltaL4
    deltaL4 = deltaL4+step4Leftover

    if deltaL4 >= stepSize:
      step4 = 1
      step4Leftover = deltaL4-stepSize #deltaL4%stepSize
    #need to add code to update loffsets if deltaL1 < 0 or if there is a remainder
    elif deltaL4 <= -stepSize:
        step4 = -1
        step4Leftover = deltaL4+stepSize #deltaL4%-stepSize
         #need to add code to update loffsets if deltaL1 < 0 or if there is a remainder
    else:
      step4Leftover = deltaL4
      #print "4 didn't move"
      
    moveStep(float(delay)/1000.0, step1, step3, step4)
    #print "x: "
    #print x
    #print "y: "
    #print y
    x = x + deltaX/steps
    y = y + deltaY/steps

def moveCircle(degrees):
  
  global x
  global y
  global step1Leftover
  global step3Leftover
  global step4Leftover
  radius = math.sqrt(math.pow((x-xHome),2)+math.pow((y-yHome),2))
  startAngle = 0
  if y >= yHome:
    startAngle = math.acos((x-xHome)/radius)*180/math.pi #degrees
  elif y < yHome:
    startAngle = 360 - math.acos((x-xHome)/radius)*180/math.pi #degrees
  angle = startAngle
  degrees = float(degrees)
  steps = int(abs(((degrees/360)*2*math.pi*radius)/stepSize))
  
  for i in range(0, steps):
    step1 = 0
    step3 = 0
    step4 = 0

    deltaX = radius*math.cos((angle+degrees/steps)*math.pi/180)-radius*math.cos((angle)*math.pi/180)
    deltaY = radius*math.sin((angle+degrees/steps)*math.pi/180)-radius*math.sin((angle)*math.pi/180) 

    deltaL1 = (x/math.sqrt(math.pow(x,2)+math.pow(y,2)))*(deltaX)+(y/math.sqrt(math.pow(x,2)+math.pow(y,2)))*((deltaY))

    deltaL1 = deltaL1+step1Leftover
    if deltaL1 >= stepSize:
      step1 = 1
      step1Leftover = deltaL1-stepSize #deltaL1%stepSize
    elif deltaL1 <= -stepSize:
      step1 = -1
      step1Leftover = deltaL1+stepSize #deltaL1%-stepSize
    else:
      step1Leftover = deltaL1
      #print "1 didn't move"
      
    deltaL3 = -((X3-x)/math.sqrt(math.pow(x,2)-2*X3*x+math.pow(y,2)-2*Y3*y+math.pow(X3,2)+math.pow(Y3,2)))*(deltaX)-((Y3-y)/math.sqrt(math.pow(x,2)-2*X3*x+math.pow(y,2)-2*Y3*y+math.pow(X3,2)+math.pow(Y3,2)))*(deltaY)

    deltaL3 = deltaL3+step3Leftover

    if deltaL3 >= stepSize:
      step3 = 1
      step3Leftover = deltaL3-stepSize #deltaL3%stepSize
    elif deltaL3 <= -stepSize:
        step3 = -1
        step3Leftover = deltaL3+stepSize #deltaL3%-stepSize
    else:
      step3Leftover = deltaL3
      #print "3 didn't move"
      
    deltaL4 = -((X4-x)/math.sqrt(math.pow(x,2)-2*X4*x+math.pow(y,2)+math.pow(X4,2)))*(deltaX)+(y/(math.sqrt(math.pow(x,2)-2*X4*x+math.pow(y,2)+math.pow(X4,2))))*(deltaY)

    deltaL4 = deltaL4+step4Leftover

    if deltaL4 >= stepSize:
      step4 = 1
      step4Leftover = deltaL4-stepSize #deltaL4%stepSize
    #need to add code to update loffsets if deltaL1 < 0 or if there is a remainder
    elif deltaL4 <= -stepSize:
        step4 = -1
        step4Leftover = deltaL4+stepSize #deltaL4%-stepSize
         #need to add code to update loffsets if deltaL1 < 0 or if there is a remainder
    else:
      step4Leftover = deltaL4
      #print "4 didn't move"
      
    moveStep(float(delay)/1000.0, step1, step3, step4)


    angle = angle + degrees/steps
    x = x + deltaX
    y = y + deltaY

def moveCircle2(radius2, degrees):
  
  global x
  global y
  global step1Leftover
  global step3Leftover
  global step4Leftover
  #radius = math.sqrt(math.pow((x-xHome),2)+math.pow((y-yHome),2))
  startAngle = 0
  radius = math.sqrt(math.pow((x-xHome),2)+math.pow((y-yHome),2))

  if y >= yHome:
    startAngle = math.acos((x-xHome)/radius)*180/math.pi #degrees
  elif y < yHome:
    startAngle = 360 - math.acos((x-xHome)/radius)*180/math.pi #degrees
  angle = startAngle
  degrees = float(degrees)
  steps = int(abs(((degrees/360)*2*math.pi*radius2)/stepSize))
  
  for i in range(0, steps):
    step1 = 0
    step3 = 0
    step4 = 0

    deltaX = radius2*math.cos((angle+degrees/steps)*math.pi/180)-radius2*math.cos((angle)*math.pi/180)
    deltaY = radius2*math.sin((angle+degrees/steps)*math.pi/180)-radius2*math.sin((angle)*math.pi/180) 

    deltaL1 = (x/math.sqrt(math.pow(x,2)+math.pow(y,2)))*(deltaX)+(y/math.sqrt(math.pow(x,2)+math.pow(y,2)))*((deltaY))

    deltaL1 = deltaL1+step1Leftover
    if deltaL1 >= stepSize:
      step1 = 1
      step1Leftover = deltaL1-stepSize #deltaL1%stepSize
    elif deltaL1 <= -stepSize:
      step1 = -1
      step1Leftover = deltaL1+stepSize #deltaL1%-stepSize
    else:
      step1Leftover = deltaL1
      #print "1 didn't move"
      
    deltaL3 = -((X3-x)/math.sqrt(math.pow(x,2)-2*X3*x+math.pow(y,2)-2*Y3*y+math.pow(X3,2)+math.pow(Y3,2)))*(deltaX)-((Y3-y)/math.sqrt(math.pow(x,2)-2*X3*x+math.pow(y,2)-2*Y3*y+math.pow(X3,2)+math.pow(Y3,2)))*(deltaY)

    deltaL3 = deltaL3+step3Leftover

    if deltaL3 >= stepSize:
      step3 = 1
      step3Leftover = deltaL3-stepSize #deltaL3%stepSize
    elif deltaL3 <= -stepSize:
        step3 = -1
        step3Leftover = deltaL3+stepSize #deltaL3%-stepSize
    else:
      step3Leftover = deltaL3
      #print "3 didn't move"
      
    deltaL4 = -((X4-x)/math.sqrt(math.pow(x,2)-2*X4*x+math.pow(y,2)+math.pow(X4,2)))*(deltaX)+(y/(math.sqrt(math.pow(x,2)-2*X4*x+math.pow(y,2)+math.pow(X4,2))))*(deltaY)

    deltaL4 = deltaL4+step4Leftover

    if deltaL4 >= stepSize:
      step4 = 1
      step4Leftover = deltaL4-stepSize #deltaL4%stepSize
    #need to add code to update loffsets if deltaL1 < 0 or if there is a remainder
    elif deltaL4 <= -stepSize:
        step4 = -1
        step4Leftover = deltaL4+stepSize #deltaL4%-stepSize
         #need to add code to update loffsets if deltaL1 < 0 or if there is a remainder
    else:
      step4Leftover = deltaL4
      #print "4 didn't move"
      
    moveStep(float(delay)/1000.0, step1, step3, step4)


    angle = angle + degrees/steps
    x = x + deltaX
    y = y + deltaY

def moveCircle3(radius3, degrees, dirCtrAngle):
  #This makes direction the direction from  current position the center should be 1 radius3 away in the direction dirCtrAngle
  
  global x
  global y
  global step1Leftover
  global step3Leftover
  global step4Leftover
  #radius = math.sqrt(math.pow((x-xHome),2)+math.pow((y-yHome),2))
  startAngle = 0
  #radius = math.sqrt(math.pow((x-xHome),2)+math.pow((y-yHome),2))

  if 0 <= dirCtrAngle < 180:
    startAngle = dirCtrAngle + 180 #degrees
  elif 180 <= dirCtrAngle < 360 :
    startAngle = dirCtrAngle - 180 #degrees
  angle = startAngle
  degrees = float(degrees)
  steps = int(abs(((degrees/360)*2*math.pi*radius3)/stepSize))
  
  for i in range(0, steps):
    step1 = 0
    step3 = 0
    step4 = 0

    deltaX = radius3*math.cos((angle+degrees/steps)*math.pi/180)-radius3*math.cos((angle)*math.pi/180)
    deltaY = radius3*math.sin((angle+degrees/steps)*math.pi/180)-radius3*math.sin((angle)*math.pi/180) 

    deltaL1 = (x/math.sqrt(math.pow(x,2)+math.pow(y,2)))*(deltaX)+(y/math.sqrt(math.pow(x,2)+math.pow(y,2)))*((deltaY))

    deltaL1 = deltaL1+step1Leftover
    if deltaL1 >= stepSize:
      step1 = 1
      step1Leftover = deltaL1-stepSize #deltaL1%stepSize
    elif deltaL1 <= -stepSize:
      step1 = -1
      step1Leftover = deltaL1+stepSize #deltaL1%-stepSize
    else:
      step1Leftover = deltaL1
      #print "1 didn't move"
      
    deltaL3 = -((X3-x)/math.sqrt(math.pow(x,2)-2*X3*x+math.pow(y,2)-2*Y3*y+math.pow(X3,2)+math.pow(Y3,2)))*(deltaX)-((Y3-y)/math.sqrt(math.pow(x,2)-2*X3*x+math.pow(y,2)-2*Y3*y+math.pow(X3,2)+math.pow(Y3,2)))*(deltaY)

    deltaL3 = deltaL3+step3Leftover

    if deltaL3 >= stepSize:
      step3 = 1
      step3Leftover = deltaL3-stepSize #deltaL3%stepSize
    elif deltaL3 <= -stepSize:
        step3 = -1
        step3Leftover = deltaL3+stepSize #deltaL3%-stepSize
    else:
      step3Leftover = deltaL3
      #print "3 didn't move"
      
    deltaL4 = -((X4-x)/math.sqrt(math.pow(x,2)-2*X4*x+math.pow(y,2)+math.pow(X4,2)))*(deltaX)+(y/(math.sqrt(math.pow(x,2)-2*X4*x+math.pow(y,2)+math.pow(X4,2))))*(deltaY)

    deltaL4 = deltaL4+step4Leftover

    if deltaL4 >= stepSize:
      step4 = 1
      step4Leftover = deltaL4-stepSize #deltaL4%stepSize
    #need to add code to update loffsets if deltaL1 < 0 or if there is a remainder
    elif deltaL4 <= -stepSize:
        step4 = -1
        step4Leftover = deltaL4+stepSize #deltaL4%-stepSize
         #need to add code to update loffsets if deltaL1 < 0 or if there is a remainder
    else:
      step4Leftover = deltaL4
      #print "4 didn't move"
      
    moveStep(float(delay)/1000.0, step1, step3, step4)


    angle = angle + degrees/steps
    x = x + deltaX
    y = y + deltaY



def goHome():
  global x
  global y
  global step1Leftover
  global step3Leftover
  global step4Leftover
  radius = math.sqrt(math.pow((x-xHome),2)+math.pow((y-yHome),2))
  startAngle = 0
  if y >= yHome:
    startAngle = math.acos((x-xHome)/radius)*180/math.pi #degrees
  elif y < yHome:
    startAngle = 360 - math.acos((x-xHome)/radius)*180/math.pi #degrees
  moveLine(radius,180+startAngle)
  
while True:  #distance = 2.5 #inches
# angle = 60 #degrees
# moveLine(-2.25,160)
# moveCircle(270)
# moveCircle2(1,270)
# moveCircle3(1.4,-220,40)
# goHome()
# time.sleep(3)


#  goHome()
#  moveLine(-1,300)
# moveLine(.5,210)
# moveLine(-.25,300)
# moveLine(1,30)
# moveLine(-.25,300)
# moveLine(2,210)
# moveLine(-.25,300)
# moveLine(2,30)

# Above was commented

  moveLine(.0625,90) # movement to indicate that clear_coordinates is called.
 # moveCircle(360)
  goHome() # movement to indicate that clear_coordinates is called.
 
  
  F = open("/home/pi/Ridiculous/current_coords.txt","w")
  F.write(str(x))
  F.write("\n")
  F.write(str(y))
  F.write("\n")
  F.write(str(step1Leftover))
  F.write("\n")
  F.write(str(step3Leftover))
  F.write("\n")
  F.write(str(step4Leftover))
  F.close()
  break

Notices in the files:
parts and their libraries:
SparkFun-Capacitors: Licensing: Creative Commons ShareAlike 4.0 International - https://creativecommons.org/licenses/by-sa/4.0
